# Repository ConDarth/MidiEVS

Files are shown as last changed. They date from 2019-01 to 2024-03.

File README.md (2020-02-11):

# MidiEVS
This repository holds the files and code for my Electronic Valve Synthesizer (EVS). 
This work is based on the work of Neil Steiner in creation of the first Electronic Valve Instrument (EVI), 
and Johan Berglund in his revival of the instrument (nuEVI).
My EVS began as an attempt to mimic Johan Berglund and create a Midi controller in the style of a trumpet, 
but it grew beyond that. Currently the goal of this project is to create a midi controller synthesizer. 
It will idealy be controlable in an identical fashion to Johan Berglunds nuEVI,
while also containing within a fully polyphonic synthesizer.
This synth would be controllable from buttons and dials fitted to the top open space of the EVS's panel.
In theory the synth would provide either USB midi output, 5-pin DIN midi output, audio jack sound output from the synthesizer, 
or output from on board speakers. 

Info on what an EVI is - 
https://electronicmusic.fandom.com/wiki/EVI

Berglund Instruments Homepage - 
http://berglundinstruments.mediarif.com/products/

Neil Steiner Info - 
https://www.patchmanmusic.com/NyleSteinerHomepage.html

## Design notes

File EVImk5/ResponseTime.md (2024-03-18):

# EVImk5 Synth Response Times

This document is a record of testing the response times of the EVI. I will measure the response times of the analog interrupt circuitry, the digital interrupt based MIDI send, the digital synthesis, and the class D amplifier. I have read that the absolute limit of human hearing is delays of 3 milliseconds so my goal is to get the delay under 5 milliseconds between the the pressure crossing the threshold and the speaker playing sound. 

## Analog Interrupt circuitry

To test the analog interrupt circuitry I have hooked an oscope probe to directly to the output of the pressure sensor, and to the interrupt line for the breath control. I expect this to be on the order of nanoseconds since I am using a high response time LM393P comparator and a CD4043BE SR latch. 

| SmoothAttack |
|:--:|
| *A smooth attack shown with analog output and interrupt output. The Intterupt slope is many orders of magnitude smaller than the smooth attack* |

| FastAttack |
|:--:|
| *A sharp attack shown with analog output and interrupt output. The Interrupt slope is orders of magnitude larger than the attack.* |

As you can see in the above pictures the interrupt is orders of magnitude faster than my attcks are, so this delay is negligible. This allows us to just measure time in relation to the sharp peak of the interrupt which is good. 

## MIDI Delay

Now to measure the delay introduced by sending the MIDI data out of the system. I will hook up the probe to the interrupt signal and meaure the time till the start and the end of the first MIDI message out of the system. 

I was able to enable the Serial Decoder and was able to verify that 9 Bytes were sent in this time frame corresponding to the 3 MIDI messages I intended to send: note on, breath LSB and breath MSB. 

| MIDIStart |
|:--:|
| *Cursor measuring the time until the start of the MIDI message from the rising edge of the interrupt. Includes the exact MIDI Bytes sent over serial. Time measured is 18.2 microseconds.* |

| MIDIEnd |
|:--:|
| *Cursor measuring the time until the start of the MIDI message from the rising edge of the interrupt. Includes the exact MIDI Bytes sent over serial. The time measured until the end of the MIDI messages is 107.2 microseconds.* |

I was able to get the MIDI message length so small since by setting the BAUD rate to 1,000,000 bits per second. I was able o do this since this MIDI line only goes directly between the teensy "brain" and the teensy "synth". Even when performing many trials the values did not change at this resolution so I can say with confidence the value will always be $18.2 \pm 0.2 \mu\text{s}$ and till the end of the MIDI message will be $ 107.2 \pm 0.2 \mu\text{s} $. 

## Digital Synthesis Delay

To perform this test most accurately I set the synthesizer to disregard breath data, and play a full volume saw wave as soon as the note on command is heard. I also add in a few effects for a second test to see how that might effect the response time. 

| SynthesisDelay |
|:--:|
| *Measuring the Delay between interrupt and the synthesis of notes. This had a large variation and I obtained a value of $ 7.6 \pm 0.8 \text{ms} $* |

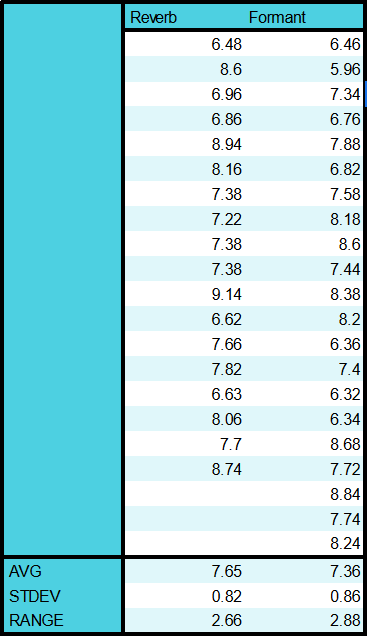
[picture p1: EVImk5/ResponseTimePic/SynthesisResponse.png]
SynthesisData
|  |
|:--:|
| *Raw data from testing the delay of note syntheis. Both with and without effects were indistinguishable.* |

With and without effects I was very well within 1/5 of a standard deviation of each other so I conclude that the number of effects has no effect on the delay to sound synthesis. I also noticed the range of data taken was $ 2.9 \text{ms} $ for both which is exactly the block delay from one audio sample bloack of 128 values at 44.1kHz which is what I am using, which leads me to conclude that that starting the note at different times within the audio blok is causing the variation. Since the sample rate never dipped below 5.8ms I also want to conclude that It took there were 2 audio block delays from first detecting note on for the system to start playing the note. 

## I2S Delay

I also tried detecting just the delay to the I2S line before sound synthesis but that is constantly outputting data so I could not easily when that started sending data to turn on the note. 

## Conclusion 

My delay is longer than I had hoped for by up to 40%, but it is still indistiguishable to my ear so that is good enough for now. In order to get better delay it seems as if I will need to decrease the audio block size. I predict that a block size of 64 instead of 128 will have delays of 3ms to 4.5ms which gets me within my target delay range if possible. 

## Addendum 

I have neglected one very important factor in this analysis, the fact that sound is not instantaneously produced by a trumpet. According to Wikipedia trumpet page the sound in a trumpet is produced by a standing wave produced in the the resonance cavity of the trumpets tubing, which means that for sound to start being produced the wave starting at your lips buzzing must at least travel to the bell of the instrument. This wave can only travel at the speed of sound though which is relatively slow. A trumpets tubing is approximately 1.48m long, and the speed of sound is roughly 343m/s. This together would give a delay of 4.3 milliseconds between buzzing and sound production from the bell of the instrument, the analog of the speaker of the EVI. This brings our 6-9 millisecond delay within 5 milliseconds of a trumpets delay. So I am happy with the delay of my EVI so far. It would be nice to get decrease the block size in the synthesizer to see what happens but that seems to be a major endeaver so for now I am satisfyed. (3/17/24)

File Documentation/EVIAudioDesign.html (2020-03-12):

Audio System Design Tool for Teensy Audio Library (http://www.pjrc.com/teensy/td_libs_Audio.html)

- Sidebar
- Keyboard Shortcuts
- Help... (http://node-red.github.io/docs)

Export Import



input

i2s

i2s_quad

adc

adcs

i2sslave

pdm

tdm

usb

output

i2s

i2s_quad

spdif

pt8211

dac

dacs

pwm

i2sslave

tdm

adat

usb

mixer

amp

mixer

play

playMem

playSdWav

playSdRaw

playFlashRaw

queue

record

queue

synth

wavetable

drum

string

sine

sine_hires

sine_fm

waveform

waveformMod

pwm

tonesweep

dc

noise

pink

effect

fade

chorus

flange

reverb

freeverb

freeverbs

envelope

multiply

delay

delayExt

bitcrusher

midside

waveshape

granular

combine

filter

biquad

fir

filter

analyze

peak

rms

fft256

fft1024

tone

notefreq

print

control

sgtl5000

ak4558

cs4272

wm8731

wm8731m

cs42448

- info

Drop the flow here

The workspace contains no input/output nodes!

You need an input or an output to export the data!

Without such a input/output function the exported code will not run properly!

##### Keyboard Shortcuts Open help in new window » (http://node-red.github.io/docs)

? | Help | Ctrl a | Select all nodes
Ctrl Space | Toggle sidebar | Shift Click | Select all connected nodes
Ctrl z | Undo | Ctrl Click | Add/remove node from selection
| | Delete | Delete selected nodes or link
Ctrl x | Cut selected nodes
Ctrl c | Copy selected nodes | Ctrl v | Paste nodes
Ctrl i | Import nodes | Ctrl e | Export selected nodes
Ctrl + | Zoom in | Ctrl - | Zoom out

Close

A called already exists. Overwrite?

Folder

Filename

- Library

Confirm deployclose

Some of the nodes are not properly configured. Are you sure you want to deploy?

The workspace contains some unknown node types:

Are you sure you want to deploy?

Confirm deployCancel

Rename sheetclose

Name:

DeleteOkCancel

Confirm deleteclose

Are you sure you want to delete ''?

OkCancel

Edit AudioMixer4 nodeclose

Name

OkCancel

close

OkCancel

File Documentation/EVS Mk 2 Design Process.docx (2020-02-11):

EVS Mk 2 Design Process

- CAD the chassis in correct shape
  1. This will hold all the components
  2. Must include – 5-pin DIN out, usb Midi out, audio jack out
- Figure out how to mount the Cannister Grip using a slip ring
  3. Redesign cannister to fit this design
- Make new mouthpiece
  4. ~Must~ be comfortable
  5. Include working bite sensor
  6. Include modulation lip
- Build up the synthesizer to be put inside
  7. Must have head phone jack out
- Design Internals of the EVS
  8. Block diagram of all internal components
  9. Design layout of said internal components
  10. Create schematic for components
  11. Create PCB for components

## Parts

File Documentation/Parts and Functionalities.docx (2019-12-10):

EVI Control Parts and Functionalities

- Teensyduino 3.6 microcontroller
  - Direct battery power
  - Native USB host for Midi output
  - 4 Variable touch sensor input
    - Pitch-bend pads, Bite Sensor, Extra Modulator
  - 3.3v tolerant only
- MPX5010GP pressure Sensor
  - Needs capacitive decoupling
  - Interrupt to update as fast as possible (notes on/off)
  - Output to analog input
  - Output into a Schmitt Trigger with variable trigger voltage
  - Schmitt trigger outputs into digital input with interrupt
    - Immediately updates notes
- MPR121 12 port Touch sensor
  - Should each have capacitive decoupling
  - Interrupt to only retrieve data when necessary (note change)
  - 2 of these to detect all Boolean touch signals
  - 7 for valves and trill valves
  - 6 for octave sensing
  - 2 for multi-phonic control
  - IRQ attached to digital input interrupts
    - Only sample IC when IRQ pulled Low
- 5 pin DIN female connector
  - No capacitive decoupling needed
  - No Interrupt
  - MIDI output for legacy midi
  - TX1 used at 31250 baud
- 3 Push Buttons
  - No capacitive decoupling
  - Interrupt to detect when pressed (note change)
  - On octave cannister
  - Changes chord quality
- Joy-con Joystick
  - Needs capacitive decoupling
  - No interrupt
  - Need special adapter to use
  - X and Y analog output
    - For Portamento/Vibrato and Menu Control
  - Switch digital output
    - For selecting 4 way setting and Menu Selector
- 8x8 Bi-Color Display
  - Should use capacitive decoupling
  - No interrupt
  - Realtime diagnostic display
  - Displays equalizer/status for pressure
  - 4-way on the go settings changer (customizable in Menu)
- 10k Potentiometer Knob
  - Needs capacitive decoupling
  - No Interrupt
  - Changes which of 4 settings is selected
- I2C FRAM
  - Possibly capacitive decoupling
  - No Interrupt
  - Stores non-volatile data for entire system
  - Alternate sheet for specific location of data
- 128x64 OLED Display
  - Should have capacitive decoupling
  - No Interrupt (software to only update when necessary)
  - Menu to change internal settings and parameters
    - Range for all variable inputs
    - Multi-phonic mode selection
    - Chord and chord preset selection
    - Breath Curve modification
    - Transposition
    - 4-way settings customizer
- 1 Push Button
  - No capacitive decoupling
  - No Interrupt
  - Used as back button for Menu

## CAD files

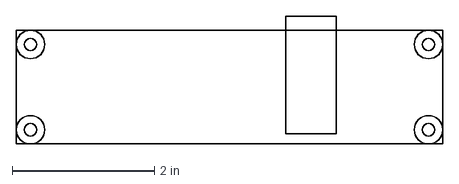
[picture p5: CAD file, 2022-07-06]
Documentation/EVIPCBLayout/EVIMainPCB.dxf
6.00 x 1.80 in

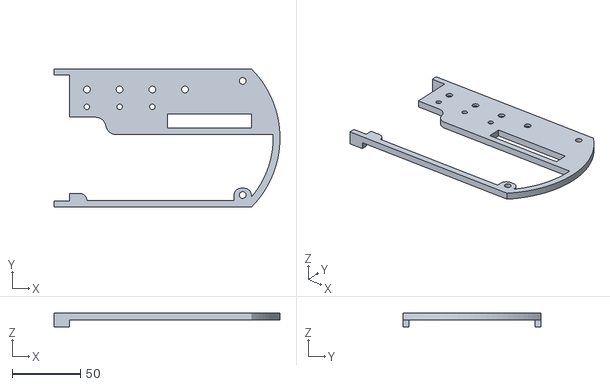
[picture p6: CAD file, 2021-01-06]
Documentation/EVI3dCAD/Body4.4.stl
165.8 x 101.6 x 10.00

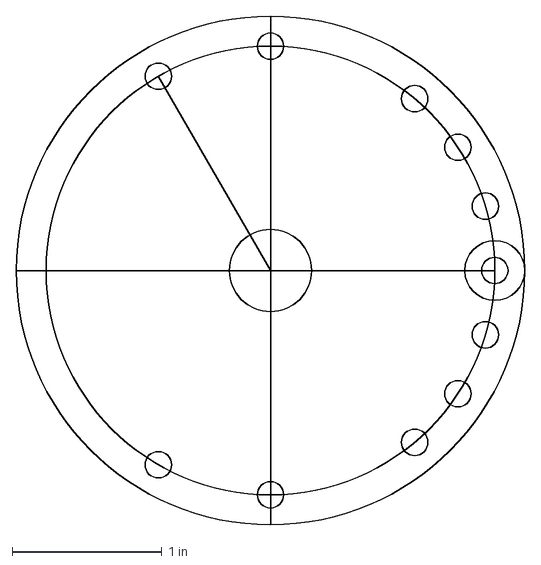
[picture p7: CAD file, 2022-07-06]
Documentation/EVIPCBLayout/EVIRollersPCB.dxf
3.40 x 3.40 in

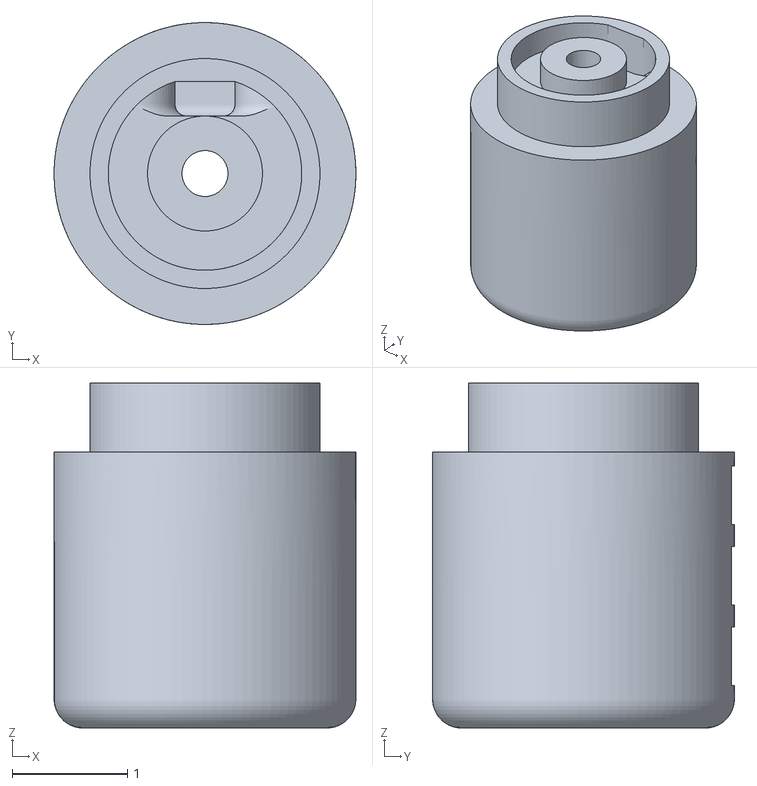
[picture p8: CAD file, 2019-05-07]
EVImk1/3d Files/CannsiterButtons.obj
2.62 x 2.62 x 3.00

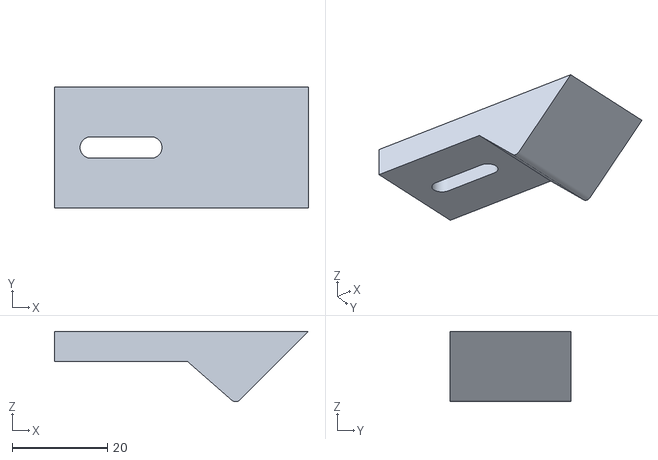
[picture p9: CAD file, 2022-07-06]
EVImk3/EVImk3PBPad2.stl
53.3 x 25.4 x 14.8

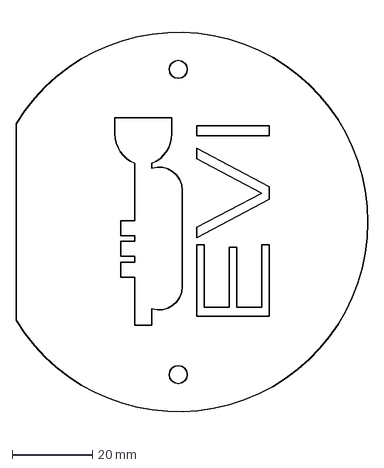
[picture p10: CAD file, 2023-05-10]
EVImk4/2D Files/EVImk4LidBatteryDecal.dxf
87.9 x 102.7 mm

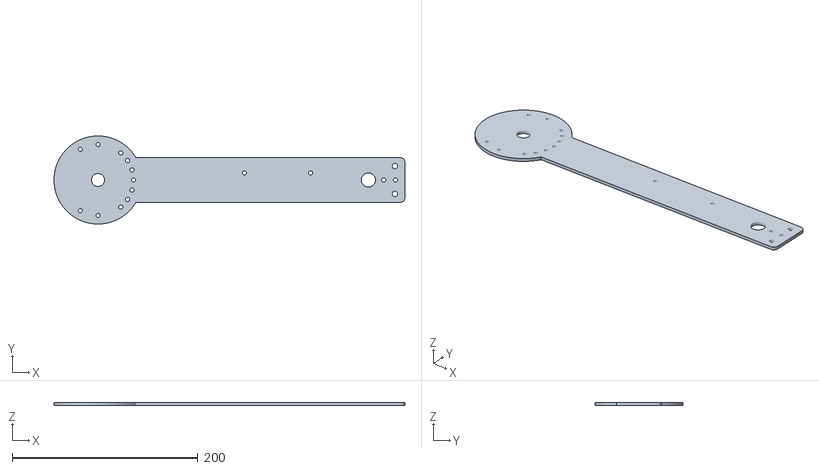
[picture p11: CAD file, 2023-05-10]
EVImk4/3D Files/EVImk4LidBottom.stl
377.6 x 94.7 x 3.17

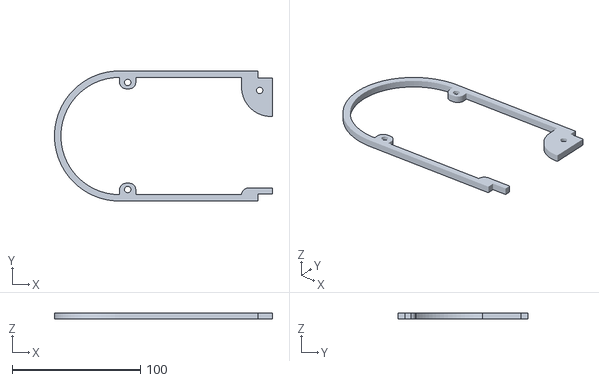
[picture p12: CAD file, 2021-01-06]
Documentation/EVI3dCAD/Body4.3.stl
170.1 x 101.6 x 5.00

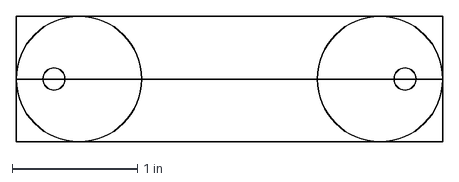
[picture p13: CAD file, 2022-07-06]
Documentation/EVIPCBLayout/EVIPitchBendPCB.dxf
3.40 x 1 in

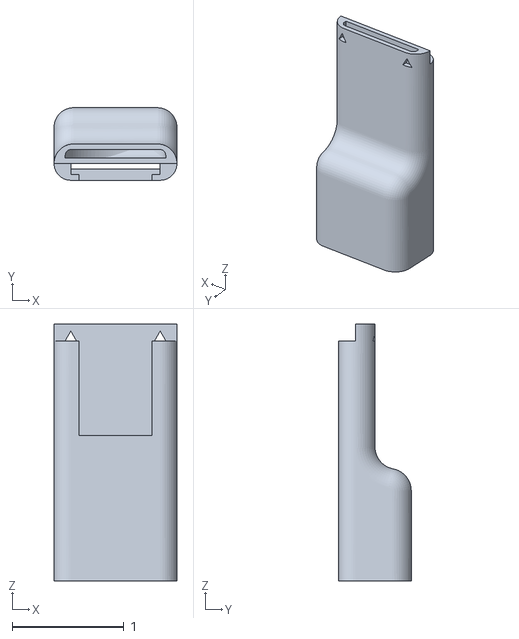
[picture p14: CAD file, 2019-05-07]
EVImk1/3d Files/Mouthpiece.obj
1.10 x 0.65 x 2.30

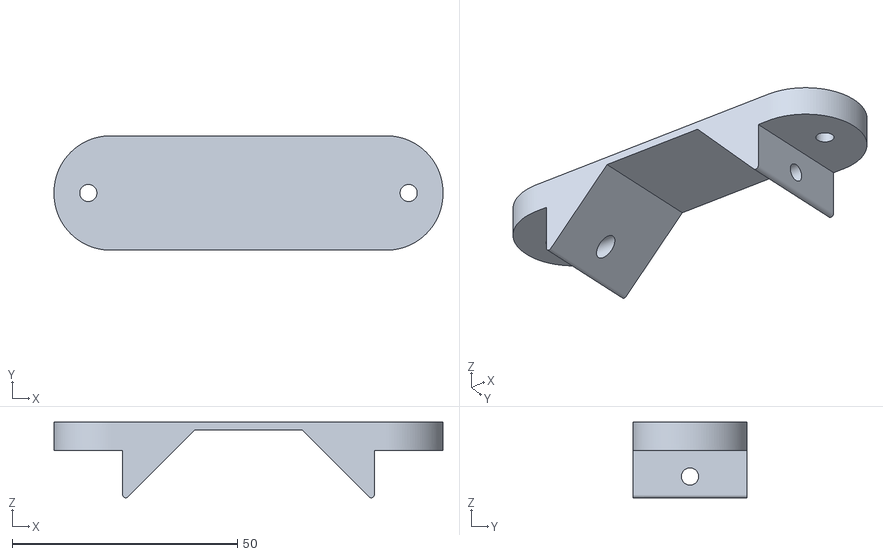
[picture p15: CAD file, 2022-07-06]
EVImk3/EVImk3PBPad4.stl
86.4 x 25.4 x 16.8

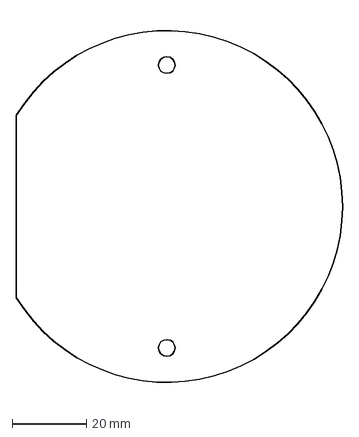
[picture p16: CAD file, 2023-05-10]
EVImk4/2D Files/EVImk4LidBattery.dxf
87.9 x 102.7 mm

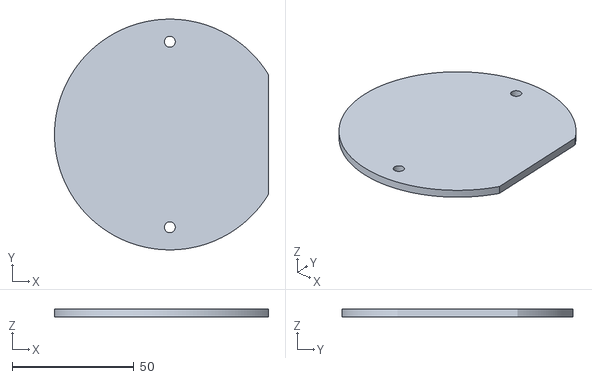
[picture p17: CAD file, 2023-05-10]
EVImk4/3D Files/EVImk4LidBattery.stl
87.9 x 94.7 x 3.18

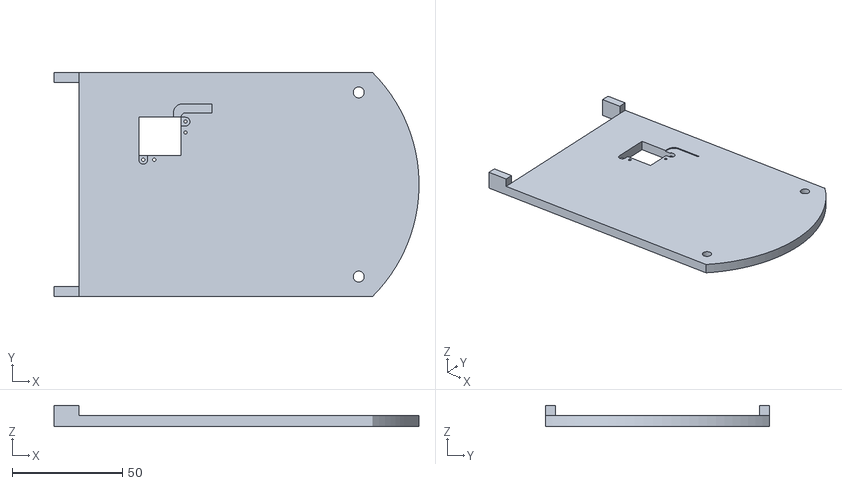
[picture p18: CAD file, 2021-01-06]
Documentation/EVI3dCAD/Body4.6.stl
165.8 x 101.6 x 9.58

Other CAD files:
Documentation/EVIPCBLayout/EVIValvePCB.dxf
EVImk1/3d Files/MouthpieceFront.obj
EVImk3/EVImk3Cannister3.stl
EVImk4/2D Files/EVImk4LidBottom.dxf
Documentation/EVI3dCAD/Body1.1.stl
Documentation/EVI3dCAD/Body1.2.stl
Documentation/EVI3dCAD/Body2.1.stl
Documentation/EVI3dCAD/Body2.2.stl
Documentation/EVI3dCAD/Body3.1.stl
Documentation/EVI3dCAD/Body3.2.stl
Documentation/EVI3dCAD/Body3.3.stl
Documentation/EVI3dCAD/Body3.4.stl
Documentation/EVI3dCAD/Body4.1.stl
Documentation/EVI3dCAD/Body4.2.stl
Documentation/EVI3dCAD/Body4.5.stl
Documentation/EVI3dCAD/Cannister1.1.stl
Documentation/EVI3dCAD/Mouthpeice1.0.stl
Documentation/EVI3dCAD/WarpTester1.0.stl
EVImk1/3d Files/BasicCannsiter.obj
EVImk1/3d Files/MouthpieceTop.obj
EVImk3/EVImk3BackPlate.stl
EVImk3/EVImk3Cannister.stl
EVImk3/EVImk3Cannister2.stl
EVImk3/EVImk3Cannister4.stl
EVImk3/EVImk3Mouthpeice.stl
EVImk3/EVImk3Mouthpeice2.stl
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

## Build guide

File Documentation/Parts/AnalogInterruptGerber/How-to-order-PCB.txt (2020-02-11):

How to Order PCB

Please refer to:
https://docs.easyeda.com/en/PCB/Order-PCB

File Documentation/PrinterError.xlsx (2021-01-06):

Square Pillar |  |  |  |  | Square Indent
TrueVal | Xval | Xerr | Yval | Yerr | TrueVal | Xval | Xerr | Yval | Yerr
3 | 2.96 | -0.04 | 2.98 | -0.02 | 3 | 3.03 | 0.03 | 3.11 | 0.11
4 | 4.05 | 0.05 | 4.08 | 0.08 | 4 | 4.07 | 0.07 | 4.08 | 0.08
5 | 4.98 | -0.02 | 5.08 | 0.08 | 5 | 5 | 0 | 4.98 | -0.02
7 | 6.95 | -0.05 | 7 | 0 | 7 | 6.99 | -0.01 | 6.96 | -0.04
10 | 9.84 | -0.16 | 9.93 | -0.07 | 10 | 9.96 | -0.04 | 9.95 | -0.05
20 | 19.9 | -0.1 | 19.8 | -0.2 | 20 | 19.89 | -0.11 | 19.81 | -0.19
Circle Pillar |  |  |  |  | Circle Indent
TrueVal | Xval | Xerr | Yval | Yerr | TrueVal | Xval | Xerr | Yval | Yerr
3 | 2.78 | -0.22 | 2.76 | -0.24 | 3 | 2.73 | -0.27 | 2.85 | -0.15
4 | 3.8 | -0.2 | 3.74 | -0.26 | 4 | 3.79 | -0.21 | 3.82 | -0.18
5 | 4.85 | -0.15 | 4.75 | -0.25 | 5 | 4.78 | -0.22 | 4.79 | -0.21
7 | 6.83 | -0.17 | 6.78 | -0.22 | 7 | 6.81 | -0.19 | 6.77 | -0.23
10 | 9.74 | -0.26 | 9.85 | -0.15 | 10 | 9.83 | -0.17 | 9.9 | -0.1
20 | 19.75 | -0.25 | 19.68 | -0.32 | 20 | 19.98 | -0.02 | 19.87 | -0.13
Hex Pillar |  |  |  |  | Hex Indent
TrueVal | Xval | Xerr | Yval | Yerr | TrueVal | Xval | Xerr | Yval | Yerr
3 | 2.93 | -0.07 | 2.97 | -0.03 | 3 | 3.03 | 0.03 | 3.08 | 0.08
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

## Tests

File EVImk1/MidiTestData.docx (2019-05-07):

Middle C on pitch data

000000001111101100111101101011101010100000000

111 183 171

111111110000010011000010010100010101011111111

144 72 84

Active sensing data

000000001100000000

1

111111110011111111

254

Incorrect data note

2E 2F 38 39 3A 3B 3C 3D 3E 3F 4E 4F

96 97 98 99 9A 9B 9C 9D 9E 9F A6 A7

2E | 96 | 01110100 | 01101001
2F | 97 | 11110100 | 11101001
38 | 98 | 00011100 | 00011001
39 | 99 | 10011100 | 10011001
3A | 9A | 01011100 | 01011001
3B | 9B | 11011100 | 11011001
3C | 9C | 00111100 | 00111001
3D | 9D | 10111100 | 10111001
3E | 9E | 01111100 | 01111001
3F | 9F | 11111100 | 11111001
4E | A6 | 01110010 | 01100101
4F | A7 | 11110010 | 11100101

Crashing Midi port data

1C | 1C | 00111000 | 00111000
BF | BF | 11011111 | 11011111
1C | 8C | 00111000 | 00110001
0 | 40 | 00000000 | 00000010

1111111100000100110001111001000000000111111111111

144 60 0

1111111100000100110001111001001111111111111111111

144 60 127

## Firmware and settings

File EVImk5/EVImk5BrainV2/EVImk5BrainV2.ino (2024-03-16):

/*********************************************************
Connor Lindsay

MIDI Wind Synth Transmit Controller
**********************************************************/

#include <Wire.h>
#include "Adafruit_MPR121.h"
#include <MIDI.h>
#include <Adafruit_GFX.h>
#include <Adafruit_SSD1306.h>
#include "Adafruit_seesaw.h"
#include <Adafruit_MCP4725.h>
#include "Adafruit_FRAM_I2C.h"


//------------------------------Constant Addresses-----------------------------
#define SCREEN_WIDTH 128 // OLED display width, in pixels
#define SCREEN_HEIGHT 32 // OLED display height, in pixels

#define OLED_RESET     4 // Reset pin # (or -1 if sharing Arduino reset pin)
#define SCREEN_ADDRESS 0x3C ///< See datasheet for Address; 0x3D for 128x64, 0x3C for 128x32

#ifndef _BV
#define _BV(bit) (1 << (bit)) 
#endif

#define SS_NEO_PIN       18
#define SS_ENC0_SWITCH   12
#define SS_ENC1_SWITCH   14
#define SS_ENC2_SWITCH   17
#define SS_ENC3_SWITCH   9
#define SS_MENU_SWITCH   24

#define SEESAW_ADDR           0x49
#define SEESAW_MENU_ADDR      0x39


//----------------------------------------Object Definitions----------------------------
Adafruit_MPR121 cap = Adafruit_MPR121();
Adafruit_MPR121 cap2 = Adafruit_MPR121();
Adafruit_seesaw ss = Adafruit_seesaw(&Wire);
Adafruit_seesaw ssMenu ;
Adafruit_SSD1306 display(SCREEN_WIDTH, SCREEN_HEIGHT, &Wire, OLED_RESET);
Adafruit_MCP4725 dacLow;
Adafruit_MCP4725 dacHigh;
Adafruit_FRAM_I2C fram     = Adafruit_FRAM_I2C();

IntervalTimer dataReadTimer ;

MIDI_CREATE_INSTANCE(HardwareSerial, Serial1, MIDI) ;


//-------------------------------------------Data Read Variables-------------------------
char buff[5] ;

bool updateNoteFlag      = 0 ;
bool touchReadFlag       = 1 ;
bool dataReadFlag        = 1 ;
bool encoderReadFlag     = 1 ;
bool encoderMenuReadFlag = 1 ;

//All times in milliseconds
uint32_t dataReadTime = 1 ;  //milliseconds
uint32_t dataReadTimeStart = 0 ; 
uint32_t encoderReadTime = 50 ; 
uint32_t encoderReadTimeStart = 0 ; 
uint32_t touchReadTime = 10 ;
uint32_t touchReadTimeStart = 0 ;
uint32_t encoderMenuReadTime = 50 ;
uint32_t encoderMenuReadTimeStart = 0 ; 
uint32_t pitchbendReadTime = 5 ;
uint32_t pitchbendReadTimeStart = 0 ;


//-----------------------------------------Touch Sensor Variables-------------------------------------

uint16_t lasttouched = 0;
uint16_t currtouched = 0;

//----------------------------------------Pitch Bend Variables----------------------------------------
const int8_t pbLength = 3 ;
int8_t pbCase = 0 ;
uint16_t pbRaw = 0 ;

uint16_t pbLowVal = 0 ;
uint16_t pbLowArray[pbLength] = {0, 0, 0} ;
int8_t pbLowCase = 0 ;

uint16_t pbHighVal = 0 ;
uint16_t pbHighArray[pbLength] = {0, 0, 0} ;
int8_t pbHighCase = 0 ;


//----------------------------------------Encoder Variables-------------------------------------------

int8_t encoderDelta[5]     = {0, 0, 0, 0, 0} ;
int8_t encoderSwitch[5]    = {0, 0, 0, 0, 0} ;
bool   encoderSwitchTog[5] = {1, 1, 1, 1, 1} ;

//------------------------------------Breath Sensor Variables-----------------------------------------

//Values for fast breath reading (in Volts)
float schmittLow  = 0.87 ;
float schmittHigh = 0.90 ;
float breathRead  = 0 ; 
int16_t breathVal = 0 ;

//--------------------------------------------MIDI Note Variables-------------------------------------

int noteMaskTouch[12] = { 1,  2,  4,  8, 16, 32, 64, 128, 256, 512, 1024, 2048} ;
int noteMaskVal[12]   = {25, 32, 39, 46, 53, 60, 67, 74,  81,  88, 95,  102 } ;

int currNote = 64 ;
int lastNote = 0 ;
bool noteFlag = false ;

/******************************************************************************************************
Menu Variables
******************************************************************************************************/

bool displayUpdateFlag = 0 ;

//                        Col1 Col2 Col3 Col4 Row
bool menuUpdateFlag[5]       = {0,   0,   0,   0,   0} ;
bool menuUpdateFlagSwitch[5] = {0,   0,   0,   0,   0} ;
int8_t menuDataDel[5]        = {0,   0,   0,   0,   0} ;
int8_t menuDataLast[5]       = {0,   0,   0,   0,   0} ;

//What state should the menu be in 
// 0 - Off
// 1 - Main Menu
// 2 - Synth
// 3 - Audio Settings
// 4 - Sensor Settings
// 5 - MIDI Settings
int8_t menuCase = 0 ;
uint32_t menuSleepTime = 60000 ;
uint32_t menuSleepTimeStart = 0 ;
uint32_t menuTimeStart = 0 ;

int8_t menuTextPos[6][2]   = { { 2,  2}, { 2, 12}, { 2, 22}, { 66,  2}, { 66, 12}, { 66, 22} } ;
int8_t menuBoxPos[6][2]    = { { 0,  0}, { 0, 10}, { 0, 20}, { 64,  0}, { 64, 10}, { 64, 20} } ;
int8_t menuBoxSize[2]      =   {63, 11} ;
int8_t menuCirclePos[6][2] = { {57,  5}, {57, 15}, {57, 25}, {121,  5}, {121, 15}, {121, 25} } ;

//-----------------------------------------Main Menu Variables----------------------------------

int8_t mainMenuCursor = 0 ;
int8_t mainMenuCursorLast = 0 ;

//-----------------------------------------Synth Menu Variables----------------------------------

int8_t synthCurrRow = 0 ;
int8_t synthLastRow = 1 ;
int8_t synthNumRow  = 17 ;

int8_t synthTopRow  = 0 ;
int8_t synthBotRow  = 1 ;
int8_t synthCurrRowPos = 0 ;

int16_t presetLength = 128 ;

int8_t synthDataMin[][4] = { {0,    0,    0,    0   },           //MAIN
                             {-40,  0,    0,    -50 },           //VOL
                             {0,    0,    0,    0   },           //AMP
                             {-111, -111, -111, -111},           //TUN
                             {0,    0,    0,    0   },           //PUL
                             {-100, 0,    0,    0   },           //FIL
                             {0,    0,    0,    0   },           //ENV
                             {0,    0,    0,    0   },           //PRT
                             {0,    0,    0,    0   },           //VIB
                             {0,    0,    0,    0   },           //VIB
                             {0,    0,    0,    0   },           //TRM
                             {0,    0,    0,    0   },           //TRM
                             {-50,  0,    0,    0   },           //RNG
                             {0,    0,    0,    0   },           //WAV
                             {0,    1,    0,    0   },           //DLY
                             {0,    0,    0,    0   },           //RVB
                             {0,    0,    0,    0   }   } ;      //FMT

int8_t synthDataMax[][4] = { {0,    0,    0,    0   },           //MAIN
                             {20,   100,  100,  50  },           //VOL
                             {100,  100,  100,  100 },           //AMP
                             {111,  111,  111,  111 },           //TUN
                             {100,  4,    100,  100 },           //PUL
                             {100,  100,  100,  100 },           //FIL
                             {100,  100,  100,  100 },           //ENV
                             {100,  100,  3,    100 },           //PRT
                             {4,    100,  111,  3   },           //VIB
                             {100,  100,  100,  100 },           //VIB
                             {4,    100,  100,  3   },           //TRM
                             {100,  100,  100,  100 },           //TRM
                             {50,   100,  100,  100 },           //RNG
                             {2,    100,  3,    100 },           //WAV
                             {100,  100,  100,  100 },           //DLY
                             {100,  100,  100,  0   },           //RVB
                             {2,    9,    100,  0   }   } ;      //FMT

int8_t synthDataVal[][4] = { {0,    0,    0,    0   },           //MAIN
                             {0,    10,   100,  0   },           //VOL
                             {0,    100,  0,    0   },           //AMP
                             {0,    0,    0,    0   },           //TUN
                             {50,   0,    0,    0   },           //PUL
                             {0,    100,  0,    20  },           //FIL
                             {0,    0,    100,  0   },           //ENV
                             {10,   0,    0,    0   },           //PRT
                             {0,    0,    0,    0   },           //VIB
                             {0,    0,    0,    0   },           //VIB
                             {0,    0,    0,    0   },           //TRM
                             {0,    0,    0,    0   },           //TRM
                             {0,    0,    10,   0   },           //RNG
                             {0,    0,    0,    0   },           //WAV
                             {0,    1,    100,  0   },           //DLY
                             {5,    0,    20,   0   },           //RVB
                             {0,    0,    0,    0   }   } ;      //FMT

char synthHeaders[][21]  = { " BACK               ",             //MAIN
                             " VOL  MN PRE  BR BAL",             //VOL
                             " AMP PUL SAW SQR TRI",             //AMP
                             " TUN PUL SAW SQR TRI",             //TUN
                             " PUL DTY SHP FRQ AMT",             //PUL
                             " FIL FRQ  BR RES  BR",             //FIL
                             " ENV ATK DLY SUS RLS",             //ENV
                             " PRT SNS CRV LNK AMT",             //PRT
                             " VIB SHP FRQ AMT LNK",             //VIB
                             " VIB ATK RLS FRQ AMT",             //VIB
                             " TRM SHP FRQ AMT LNK",             //TRM
                             " TRM ATK RLS FRQ AMT",             //TRM
                             " RNG POL STP MAX NSE",             //RNG
                             " WAV SHP AMT LNK AMT",             //WAV
                             " DLY FDB TME FRQ RES",             //DLY
                             " RVB  RM DMP AMP    ",             //RVB
                             " FMT SEX VOW AMT    "     } ;      //FMT

//MIDI CC Channels to send to and exceptions to standard sending procedure
int8_t synthDataCC[][4]  = { {-1,   -1,   -1,   -1  },           //MAIN
                             {7,    9,    10,   8   },           //VOL
                             {16,   17,   18,   19  },           //AMP
                             {20,   21,   22,   23  },           //TUN
                             {106,  107,  108,  109 },           //PUL
                             {14,   12,   15,   13  },           //FIL
                             {73,   74,   75,   72  },           //ENV
                             {6,    5,    89,   90  },           //PRT
                             {110,  111,  112,  113 },           //VIB
                             {114,  115,  116,  116 },           //VIB
                             {56,   57,   58,   59  },           //TRM
                             {60,   61,   62,   63  },           //TRM
                             {98,   99,   100,  101 },           //RNG
                             {85,   86,   87,   88  },           //WAV
                             {76,   77,   78,   79  },           //DLY
                             {102,  103,  104,  -1  },           //RVB
                             {91,   92,   93,   -1  }   } ;      //FMT

// Types of data to send
// 0: Standard (7bit unsigned int)
// 1: Toggle Type (0-Off 64-On)
// 2: LSB Negative (7bit positive data and 7bit negative data sent on CC+32)
// 3: Centered negative (Data from -64 to 63 has 64 added to be sent over 7 bits)
int8_t synthDataCCType[][4] = { {-1,   -1,   -1,   -1  },        //MAIN
                                {3,    0,    0,    3   },        //VOL
                                {0,    0,    0,    0   },        //AMP
                                {2,    2,    2,    2   },        //TUN
                                {0,    0,    0,    0   },        //PUL
                                {2,    0,    0,    0   },        //FIL
                                {0,    0,    0,    0   },        //ENV
                                {0,    0,    0,    0   },        //PRT
                                {0,    0,    0,    0   },        //VIB
                                {0,    0,    0,    0   },        //VIB
                                {0,    0,    0,    0   },        //TRM
                                {0,    0,    0,    0   },        //TRM
                                {3,    0,    0,    0   },        //RNG
                                {0,    0,    0,    0   },        //WAV
                                {0,    0,    0,    0   },        //DLY
                                {0,    0,    0,    -1  },        //RVB
                                {0,    0,    0,    -1  }   } ;   //FMT
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
void loop() {
  updateData() ;
  updateNote() ;
  updateMenu() ;

}

/******************************************************************************
Functions
******************************************************************************/

//---------------------------Update Functions----------------------------------

void updateNote(){
  if (updateNoteFlag){
    updateNoteFlag = 0 ;
  
    for (int i=0; i<12; i++){
      if (currtouched >= noteMaskTouch[i]){
        currNote = noteMaskVal[i] ;
      }
    }

    if (noteFlag){
      if (currNote != lastNote){
        MIDI.sendNoteOn(currNote, 100, 1) ;
        MIDI.sendNoteOff(lastNote, 100, 1) ;

        usbMIDI.sendNoteOn(currNote, 100, 1) ;
        usbMIDI.sendNoteOff(lastNote, 100, 1) ;

        lastNote = currNote ;
      }
    }
  }
}

void updateData(){
  if (dataReadFlag){
    dataReadFlag = 0 ;
    dataReadTimeStart = millis() ;

    if (noteFlag){
      breathRead = ADCToVoltage( analogRead(22) ) ;
      breathVal = breathAmount(breathRead) ;
      MIDI.sendControlChange(34, 0x7f & breathVal, 1) ;
      MIDI.sendControlChange(2, 0x7f & (breathVal >> 7), 1) ;

      usbMIDI.sendControlChange(34, 0x7f & breathVal, 1) ;
      usbMIDI.sendControlChange(2, 0x7f & (breathVal >> 7), 1) ;
    }

    
    //Read data only at set times to clear up processing power
    if (touchReadFlag){
      if (dataReadTimeStart - touchReadTimeStart >= touchReadTime){
        touchReadFlag = 0 ;

        currtouched = cap.touched();

        if (currtouched != lasttouched){
          updateNoteFlag = 1 ;
          // reset our state
          lasttouched = currtouched;
        }
      }
    }

    if (encoderReadFlag){
      if (dataReadTimeStart - encoderReadTimeStart >= encoderReadTime){
        encoderReadFlag = 0 ;

        encoderSwitch[0] = ss.digitalRead(SS_ENC0_SWITCH) ;
        encoderSwitch[1] = ss.digitalRead(SS_ENC1_SWITCH) ;
        encoderSwitch[2] = ss.digitalRead(SS_ENC2_SWITCH) ;
        encoderSwitch[3] = ss.digitalRead(SS_ENC3_SWITCH) ;

        for (int8_t i=0; i<4; i++) {
          //Get the change in encoder position to be used in menuUpdate
          encoderDelta[i] = ss.getEncoderDelta(i) ;
          menuDataDel[i] = encoderDelta[i] ;

          if (menuDataDel[i] != 0){
            menuUpdateFlag[i] = 1 ;
          }

          if (encoderSwitch[i] && !encoderSwitchTog[i]){
            menuUpdateFlagSwitch[i] = 1 ;
            menuUpdateFlag[i] = 1 ;
            encoderSwitchTog[i] = 1 ;
          } else if (!encoderSwitch[i] && encoderSwitchTog[i]){
            encoderSwitchTog[i] = 0 ;
          }
        }

      }
    }

    if (encoderMenuReadFlag){
      if (dataReadTimeStart - encoderMenuReadTimeStart >= encoderMenuReadTime){
        encoderMenuReadFlag = 0 ;
        encoderDelta[4] = ssMenu.getEncoderDelta() ;
        menuDataDel[4] = encoderDelta[4] ;

        encoderSwitch[4] = ssMenu.digitalRead(SS_MENU_SWITCH) ;

        if (menuDataDel[4] != 0){
          menuUpdateFlag[4] = 1 ;
        }

        if (encoderSwitch[4] && !encoderSwitchTog[4]){
          menuUpdateFlagSwitch[4] = 1 ;
          menuUpdateFlag[4] = 1 ;
          encoderSwitchTog[4] = 1 ;
        } else if (!encoderSwitch[4] && encoderSwitchTog[4]){
          encoderSwitchTog[4] = 0 ;
        }
      }
    }

    if (dataReadTimeStart - pitchbendReadTimeStart >= pitchbendReadTime){
      switch(pbCase){
        case 0:
          //Update a pitchbend low value
          pbRaw = cap2.filteredData(10) ;       //Get new raw value
          pbLowVal -= pbLowArray[pbLowCase] ;   //Subtract off last value
          pbLowVal += pbRaw ;                   //Add in New value
          pbLowArray[pbLowCase] = pbRaw ;       //Replace the value in the array

          pbCase = 1 ;
          pbLowCase = (pbLowCase+1)%pbLength ;

          Serial.print(pbLowVal) ; Serial.print("\t") ; Serial.println(pbHighVal) ;
        break;
        case 1:
          //Update pitchbend high value
          pbRaw = cap2.filteredData(11) ;       //Get new raw value
          pbHighVal -= pbHighArray[pbHighCase] ;   //Subtract off last value
          pbHighVal += pbRaw ;                   //Add in New value
          pbHighArray[pbHighCase] = pbRaw ;       //Replace the value in the array

          pbCase = 0 ;
          pbHighCase = (pbHighCase+1)%pbLength ;
        break;
      }
    }

  }
}

void updateMenu(){

  menuTimeStart = millis() ;

  if (menuCase != 0){
    if (menuTimeStart - menuSleepTimeStart >= menuSleepTime){
      menuCase = 0 ;

      display.clearDisplay() ;
      displayUpdateFlag = 1;
    } else if(menuUpdateFlag[0] || menuUpdateFlag[1] || menuUpdateFlag[2] || menuUpdateFlag[3] || menuUpdateFlag[4]){
      menuSleepTimeStart = menuTimeStart ;   
    }
  }

  switch(menuCase){
    case 0:  //Off
      offMenuUpdate() ;
    break;
    case 1:  //Main menu
      mainMenuUpdate() ;
    break;
    case 2:  //Synth Menu
      synthMenuUpdate() ;
    break;
    case 3:  //Audio Settings
      audioMenuUpdate() ;
    break;
    case 4:  //Sensor Settings
    break;
    case 5:  //MIDI Settings
    break;
  }

  //Clear all menu update data is not taken care of by other updates
  for (int8_t i=0; i<5; i++){
    menuUpdateFlag[i] = 0 ;
    menuUpdateFlagSwitch[i] = 0 ;
  }
  

  if (displayUpdateFlag){
    displayUpdateFlag = 0 ;
    display.display() ;
  }

}

void updateCC(int8_t _row, int8_t _col) {
  //Send Data differently depending on the entry type
  switch(synthDataCCType[_row][_col]){
    case 0:
      //Standard 
      MIDI.sendControlChange(synthDataCC[_row][_col], synthDataVal[_row][_col], 1) ;
      usbMIDI.sendControlChange(synthDataCC[_row][_col], synthDataVal[_row][_col], 1) ;
    break;
    case 1:
      //On/Off type data defaults to (0-63=Off, 64-127=On)
      if (synthDataVal[_row][_col]){
        MIDI.sendControlChange(synthDataCC[_row][_col], 64, 1) ;
        usbMIDI.sendControlChange(synthDataCC[_row][_col], 64, 1) ;
      } else {
        MIDI.sendControlChange(synthDataCC[_row][_col], 0, 1) ;
        usbMIDI.sendControlChange(synthDataCC[_row][_col], 0, 1) ;
      }
    break;
    case 2:
      //Send Negative values over the LSB channel
      if (synthDataVal[_row][_col] >= 0){
        MIDI.sendControlChange(synthDataCC[_row][_col], synthDataVal[_row][_col], 1) ;
        usbMIDI.sendControlChange(synthDataCC[_row][_col], synthDataVal[_row][_col], 1) ;
      } else {
        MIDI.sendControlChange(synthDataCC[_row][_col]+32, abs(synthDataVal[_row][_col]), 1) ;
        usbMIDI.sendControlChange(synthDataCC[_row][_col]+32, abs(synthDataVal[_row][_col]), 1) ;
      }
    break;
    case 3:
      //Send +/- Signals with -63/+64 range
      MIDI.sendControlChange(synthDataCC[_row][_col], synthDataVal[_row][_col]+64, 1) ;
      usbMIDI.sendControlChange(synthDataCC[_row][_col], synthDataVal[_row][_col]+64, 1) ;
    break;
    case -1:
      //dont send anything in this case
    break;
  }

  /* Print What CC is sent
  Serial.print("CC Channel: ") ;
  Serial.print(synthDataCC[_row][_col]) ;
  Serial.print("\t Value: ") ;
  Serial.println(synthDataVal[_row][_col]) ;
  */

}

/******************************************************************************************************
Menu Update Functions
******************************************************************************************************/

void offMenuUpdate(){
  for (int8_t i=0; i<5; i++){
    if (menuUpdateFlag[i]){
      menuUpdateFlag[i] = 0 ;
      menuCase = 1 ; //Wake up menu if any knobs or buttons pressed
      menuSleepTimeStart = millis() ; //Start the sleep timer
      display.clearDisplay() ;
      printMainAll() ;
    }
  }
}

void mainMenuUpdate(){
  if (menuUpdateFlag[4]){
    menuUpdateFlag[4] = 0 ;

    mainMenuCursorLast = mainMenuCursor ;
    mainMenuCursor = constrain(mainMenuCursor+menuDataDel[4], 0, 4) ;

    printMenuSelect(mainMenuCursor, mainMenuCursorLast) ;
  }

  if (menuUpdateFlagSwitch[4]){
    //Switch case to whatever menu we were on
    displayUpdateFlag = 1 ;
    display.clearDisplay() ;
    switch(mainMenuCursor){
      case 0:
        //Start Synth menu
        menuCase = 2 ; 
        printSynthAll() ;
      break;
      case 1:
        //Start Audio Settings menu
        menuCase = 3 ;
        printAudioMenu() ;
      break;
      case 2:
        //Start Sensor Settings menu
        menuCase = 4 ;
        printSensorAll() ;
      break;
      case 3:
        //Start MIDI Settings menu
        menuCase = 5 ;
        printMIDIAll() ;
      break;
      case 4:
        //Turn the menu off
        menuCase = 0 ;
      break;
    }
  }

}
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

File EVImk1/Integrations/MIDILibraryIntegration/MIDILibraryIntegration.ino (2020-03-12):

/*********************************************************
This is a library for the MPR121 12-channel Capacitive touch sensor

Designed specifically to work with the MPR121 Breakout in the Adafruit shop 
  ----> https://www.adafruit.com/products/

These sensors use I2C communicate, at least 2 pins are required 
to interface

Adafruit invests time and resources providing this open source code, 
please support Adafruit and open-source hardware by purchasing 
products from Adafruit!

Written by Limor Fried/Ladyada for Adafruit Industries.  
BSD license, all text above must be included in any redistribution
**********************************************************/

#include <Wire.h>
#include <MIDI.h>
#include "Adafruit_MPR121.h"
//#include <CapacitiveSensor.h>
#include <Adafruit_GFX.h>
#include "Adafruit_LEDBackpack.h"

/**********************************************************************************************************************************************/

#define Y_COORDINATE_THR 30 //thresholds for x cooordinate on the joystick
#define X_COORDINATE_THR 30 //threshold for y coordinate on the joystick
#define VIBRATO_AVG_SAMPLE 5 //number of samples to compound for the vibrato joystick
#define MIDI_OUTPUT_SERIAL 0 //defines which midi output to use (harlessMIDI-0 ; MIDIjack-1 ; SerialPort1-2)
#define SELECTOR_DIAL_PIN A1
#define BITE_SENSOR_PIN A2 
#define CHORD_QUALITY_PIN_1 2
#define CHORD_QUALITY_PIN_2 3
#define CHORD_QUALITY_PIN_3 4


/**********************************************************************************************************************************************/


#ifndef _BV
#define _BV(bit) (1 << (bit)) 
#endif

/*--------------------------------------------------------------------------------------------------------------------------------------------------------------------------------------------------
****************************************************************************************************************************************************************************************************
--------------------------------------------------------------------------------------------------------------------------------------------------------------------------------------------------*/

//define the npr121 sensors 
Adafruit_MPR121 cap1 = Adafruit_MPR121();
Adafruit_MPR121 cap2 = Adafruit_MPR121();
MIDI_CREATE_DEFAULT_INSTANCE();

// define the individual cap sensor 
//the sensor busses arent sensitive enough so need individual
//CapacitiveSensor   pBUpSensor = CapacitiveSensor(2, 4);        // 10M resistor between pins 4 & 2, pin 2 is sensor pin, add a wire and or foil if desired
//CapacitiveSensor   pBDownSensor = CapacitiveSensor(2, 3);        // 10M resistor between pins 4 & 2, pin 2 is sensor pin, add a wire and or foil if desired

Adafruit_BicolorMatrix matrix = Adafruit_BicolorMatrix();

/*--------------------------------------------------------------------------------------------------------------------------------------------------------------------------------------------------
****************************************************************************************************************************************************************************************************
--------------------------------------------------------------------------------------------------------------------------------------------------------------------------------------------------*/

// Keeps track of the last pins touched
// so we know when buttons are 'released'
uint16_t lasttouched1 = 0;
uint16_t currtouched1 = 0;
uint16_t lasttouched2 = 0;
uint16_t currtouched2 = 0;

/**********************************************************************************************************************************************/

boolean pressedKey[24] ; //array for storing pressed keys [0-11 octave npr121] [12-23 fingering npr121] [24-26 momentary buttons]
int keyValue[] =      {-5, -2, -1, -3,  2,  1, 4} ;  //how much to change pitch for each pitch key K1, K2, K3, K4, K5, K6, K7
int octaveValue[] =   {0, 12, 24, 36, 48, 60, 72} ;  //which ovtave to be in, adds to the base pitch
int transpositionPitch = 34 ; //starting pitch when no keys pressed

/**********************************************************************************************************************************************/

int pitch[] = {0, 0, 0, 0, 0, 0, 0, 0, 0, 0, 0, 0, 0, 0, 0, 0} ; //array for storing which pitches should be played
int pitchVelocity[] = {0, 0, 0, 0, 0, 0, 0, 0, 0, 0, 0, 0, 0, 0, 0, 0} ; //velocity each note should be played at 
boolean pitchState[128] ; //array of which pitch is currently on
int pitchStateVelocity[128] ; //the velocity each pitch in the array should be at 
int lastPitch[] = {0, 0, 0, 0, 0, 0, 0, 0, 0, 0, 0, 0, 0, 0, 0, 0} ; //array of which pitch was last on
int pitchNum = 0 ; //which pitch in the array to set 
int pitchStateNum = 0 ; //im not sure possibly depracated
boolean pitchStateCounter = false ; //possibly depracted

/**********************************************************************************************************************************************/

int currentVelocity = 100 ;
int sustainVelocity = 90 ;
int chordVelocity = 90;
boolean velocityToggle = false ;

/**********************************************************************************************************************************************/

int chordPitch[4][16] ; //array storing the pitches for each chord key 
boolean chordSetToggle[] = {0, 0, 0, 0} ; //toggle to not set chord more than once
boolean chordClearToggle[] = {0, 0, 0, 0} ; //toggle to not clear chord more than once
boolean chordOnToggle[] = {0, 0, 0, 0} ; //toggle to not play chord more than once
boolean chordAddToggle = true ;
int chordNum[] = {0, 0, 0, 0} ; //which chord to set/clear/activate
int chordMode = 1 ;
int chordPresetSize = 4 ;
                        //tone shifts from original pitch in preset chord last column is size of chord
int chordPreset[8][4] = { {0, 4, 7, 0}, //major triad
                          {0, 3, 7, 0}, //minor triad
                          {0, 4, 7,10}, //dominent chord
                          {0, 3, 6, 0}, //diminished triad
                          {0, 7,14, 0}, //open chord
                          {0, 4, 8, 0}, //augmented triad
                          {4, 7,12, 0}, //first inversion major
                          {3, 7,12, 0}  //first inversion minor
                        } ;
int chordPresetNum = 0 ; 
int chordPresetNumLast = 0 ;  
int chordPresetBase = 0 ;    
boolean chordPresetToggle = false ;                 

/**********************************************************************************************************************************************/

boolean recievingData = false ;
int newDataNum = 0 ;
int recievedDataSize = 4 ;
byte newData[4] ;
int data1 = 0 ;
int data2 = 0 ;
byte lastByte = 0 ;
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

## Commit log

2019-02-04 integrated pb with evi device
2019-02-11 added in vibrato, kinda, and select function
    [JoystickTest.ino, PBIntegration.ino, VibratoIntegration.ino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]
2019-02-18 Fixed midi issues and started basic integration of pressure sensor
    [BasicMidiIntegration.ino, BasicMidiTest.ino, BasicPressureIntegration.ino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]
2019-05-07 Added a bunch of stuff The 3d files and the menu tests
    [BasicCannsiter.obj, CannsiterButtons.obj, Mouthpiece.obj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]
2019-06-10 added in reset for the harmonizer
    [FRAMDisplayTest.ino]
2019-11-11 Untested but fixed the modeselect pot to allow for threshholds in either direction and should allow for fixing of jumpiness
    [MIDILibraryIntegration.ino]
2019-11-12 smoothed equalizer and fixed it !!
    [MIDILibraryIntegration.ino]
2019-11-22 fixed timings for EVI and got presets working
    [EVI Main Timings.xlsx]
2019-11-24 Generalized the chord setting function, now full funtionality for 4 pitches each to 8 chords for 8 presets, 4 harmonizers, and 4 rotators. Added in spreadsheet defining the address of each stored var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
    [FRAM data storage addresses.xlsx]
2019-12-08 Reorganized documents and added in extra documentation
    [BasicCannsiter.obj, CannsiterButtons.obj, EVI Breath Curve Data.xlsx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]
2019-12-10 revised display code to add in fram for transposition and reformatted the sensor adjustments
    [EVImk2.fzz, FRAM data storage addresses.xlsx]
2019-12-19 fixed up the menu and added breath curves
    [EVI Main Timings.xlsx, EVImk2v2.fzz, FRAM data storage addresses.xlsx]
2019-12-28 Started on menu class and testing out teensy features
    [FRAM data storage addresses.xlsx]
2019-12-31 did initial testing for teensy far exceeds expectations on ease of use and funcionality
    [EVImk2.1.fzz, EVImk2.2.fzz]
2020-02-11 Edited the display software some, started on the new equalizer, still need to test it for better response time, added in the gerber files for initial prototypw of analog interrupt generator, started 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
    [Gerber_BoardOutline.GKO, Gerber_BottomLayer.GBL, Gerber_BottomSilkLayer.GBO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]
2021-01-06 Its been a while, added in documentation for all components used, tested different features on the teensy synth, and started 3D modeling the body for prototype 2 of EVS
    [Body1.1.stl, Body1.2.stl, Body2.1.stl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]
2022-03-12 Worked on interrupt for pressure sensor
2022-07-06 Added lots of files for the design and manufacturing of the EVI Especially 3d models and 2d layouts for PCBs
    [EVIMainPCB.dxf, EVIPitchBendPCB.dxf, EVIRollersPCB.dxf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]
2023-05-10 Old files for design of the EVI mk4 which is now fully operational at this time
    [EVImk4BodyBack3.stl, EVImk4BodyBack4.stl, EVImk4BodyFront3.stl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]
2024-03-12 Started Fully Programming Onboard Synth
    [waveShape.xlsx, waveshapeABS.csv, waveshapeATAN.csv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]

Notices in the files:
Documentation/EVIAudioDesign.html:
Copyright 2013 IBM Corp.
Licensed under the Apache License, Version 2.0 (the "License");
